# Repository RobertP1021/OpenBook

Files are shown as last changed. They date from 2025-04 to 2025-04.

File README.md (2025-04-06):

# OpenBook

## Diagrama



## Bill Of Materials

| Componenta | Datasheet | Model |
|---|---|---|
| ESP32-C6-WROOM-1-N8 | [Datasheet](https://www.espressif.com/sites/default/files/documentation/esp32-c6_datasheet_en.pdf) | [Model](https://www.snapeda.com/parts/ESP32-C6-WROOM-1-N8/Espressif+Systems/view-part/?ref=eda) |
| W25Q512JVEIQ | [Datasheet](https://www.winbond.com/resource-files/W25Q512JV%20RevI%2005132020%20Plus.pdf) | [Model](https://www.snapeda.com/parts/W25Q512JVEIQ/Winbond+Electronics/view-part/?ref=eda) |
| DS3231SN# | [Datasheet](https://datasheets.maximintegrated.com/en/ds/DS3231.pdf) | [Model](https://www.snapeda.com/parts/DS3231SN%23/Analog+Devices/view-part/?ref=eda) |
| MAX17048G+T10 | [Datasheet](https://datasheets.maximintegrated.com/en/ds/MAX17048-MAX17049.pdf) | [Model](https://www.snapeda.com/parts/MAX17048G+T10/Analog+Devices/view-part/?ref=eda) |
| BME688 | [Datasheet](https://www.bosch-sensortec.com/media/boschsensortec/downloads/datasheets/bst-bme688-ds000.pdf) | [Model](https://www.snapeda.com/parts/BME680/Bosch/view-part/?welcome=home) |
| MCP73831 | [Datasheet](https://ww1.microchip.com/downloads/en/DeviceDoc/20001984g.pdf) | [Model](https://www.snapeda.com/parts/MCP73831T-2ACI-OT/Microchip/view-part/?ref=eda) |
| BD5229G-TR | [Datasheet](https://fscdn.rohm.com/en/products/databook/datasheet/ic/power/voltage_detector/bd52xxg-e.pdf) | [Model](https://componentsearchengine.com/part-view/BD5229G-TR/ROHM%20Semiconductor) |
| USBLC6-2SC6Y | [Datasheet](https://www.st.com/resource/en/datasheet/usblc6-2.pdf) | [Model](https://www.snapeda.com/parts/USBLC6-2SC6Y/STMicroelectronics/view-part/?ref=eda) |
| 112A-TAAR-R03 | [Datasheet](https://www.attend.com.tw/sites/default/files/2022-05/112A-TAAR-R03.pdf) | [Model](https://www.snapeda.com/parts/112A-TAAR-R03/ATTEND/view-part/?ref=eda) |
| FH34SRJ-24S-0.5SH | [Datasheet](https://www.hirose.com/product/document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) | [Model](https://www.snapeda.com/parts/FH34SRJ-24S-0.5SH(99)/Hirose/view-part/?ref=eda) |
| DMG2305UX-7 | [Datasheet](https://www.diodes.com/assets/Datasheets/DMG2305UX.pdf) | [Model](https://www.snapeda.com/parts/DMG2305UX-7/Diodes%20Inc./view-part/?ref=eda) |
| SI1308EDL-T1-GE3 | [Datasheet](https://www.vishay.com/docs/68732/si1308edl.pdf) | [Model](https://www.snapeda.com/parts/SI1308EDL-T1-GE3/Vishay+Siliconix/view-part/?ref=snap) |
| MBR0530 | [Datasheet](https://www.onsemi.com/pdf/datasheet/mbr0520lt1-d.pdf) | [Model](https://www.snapeda.com/parts/MBR0530/Onsemi/view-part/?ref=eda) |
| PGB1010603MR | [Datasheet](https://www.littelfuse.com/media?itemid=3d1e98b7-4d37-463c-9380-c56c83b11c3c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) | [Model](https://www.snapeda.com/parts/PGB1010603MR/Littelfuse/view-part/?ref=eda) |
| XC6220A331MR-G | [Datasheet](https://www.torexsemi.com/file/xc6220/XC6220.pdf) | [Model](https://www.snapeda.com/parts/XC6220A331MR-G/Torex+Semiconductor/view-part/?ref=eda) |
| EVQPUJ02K | [Datasheet](https://industrial.panasonic.com/cdbs/www-data/pdf/ATV0000/ATV0000CE5.pdf) | [Model](https://www.snapeda.com/parts/EVQPUJ02K/Panasonic/view-part/?ref=eda) |
| GDEH0154D67 | [Datasheet](https://www.good-display.com/companyfile/203.html) | [Model](https://www.good-display.com/product/207.html) |
| CPH3225A | [Datasheet](https://www.sii.co.jp/en/quartz/files/2021/03/CPH3225A_E.pdf) | [Model](https://www.snapeda.com/parts/CPH3225A/Seiko+Instruments/view-part/?ref=eda) |

## Functionalitatea hardware

Proiectul foloseste un ESP32-C6 ca microcontroller central, cu urmatoarele componente principale:

1. **Display E-Ink (GDEH0154D67)** - afisaj de 1.54" cu 200x200 pixeli conectat prin SPI, perfect pentru afisarea datelor cu consum minim de energie, deoarece consuma curent doar la actualizarea ecranului.

2. **Memorie Flash externa (W25Q512JVEIQ)** - 64MB de stocare SPI pentru date, configuratii si loguri cand dispozitivul este in modul deep sleep.

3. **Senzor de mediu (BME688)** - masoara temperatura, umiditatea, presiunea atmosferica si calitatea aerului, conectat prin I2C.

4. **Ceas RTC (DS3231)** - mentine ora exacta chiar si cand dispozitivul este oprit, conectat prin I2C.

5. **Sistem de alimentare**: 
   - Baterie LiPo 3.7V
   - Circuit de incarcare (MCP73831)
   - Monitor baterie (MAX17048G)
   - Regulator LDO 3.3V (XC6220A331MR-G)
   - Convertor 5V (pentru componente care necesita 5V)

6. **Interfata USB-C** - pentru incarcare si comunicatii, cu protectie ESD (USBLC6-2SC6Y).

7. **Butoane tactile (EVQPUJ02K)** - 3 butoane pentru interfata utilizator.

8. **Slot card microSD** - pentru stocarea datelor in volum mare.

## Descrierea pinilor ESP32-C6

- **GPIO1-2**: Magistrala I2C principala pentru conectarea senzorilor si RTC-ului DS3231, fiind pinii hardware dedicati pentru I2C.

- **GPIO3**: Pin RESET pentru reinitializarea sistemului.

- **GPIO4**: SS_SD pentru selectarea cardului microSD, parte a interfetei SPI dedicate cardului.

- **GPIO5**: Pin EPD_DC pentru controlul displayului E-Ink (Data/Command).

- **GPIO6**: Pin SPI SCK (clock) utilizat pentru comunicatia cu displayul si alte dispozitive SPI.

- **GPIO7**: Pin MOSI pentru transferul de date spre dispozitivele SPI.

- **GPIO8-9**: Pini pentru interfata RTC (32kHz si INT_RTC), utilizati pentru wake-up si sincronizare.

- **GPIO10**: Pin pentru controlul FLASH_CS, selectand memoria flash externa.

- **GPIO11**: Pin EPD_CS pentru selectarea displayului E-Ink.

- **GPIO12**: Pin EPD_RST pentru resetarea displayului E-Ink.

- **GPIO13-14**: Pini USB_D- si USB_D+ pentru comunicatia USB.

- **GPIO15**: Pin IO/BOOT pentru controlul bootarii sistemului.

- **GPIO16-18**: Pini pentru controlul displayului e-ink (EPD_3V3, EPD_BUSY).

- **GPIO19-21**: Pini SCL, SDA pentru o secunda interfata I2C folosita pentru comunicatie cu senzorii adaugati.

- **GPIO22-23**: Pini pentru control I/O general si semnale de control pentru display.

- **GPIO26-28**: Pini pentru LED-uri de status si controlul modulului.

## Poze


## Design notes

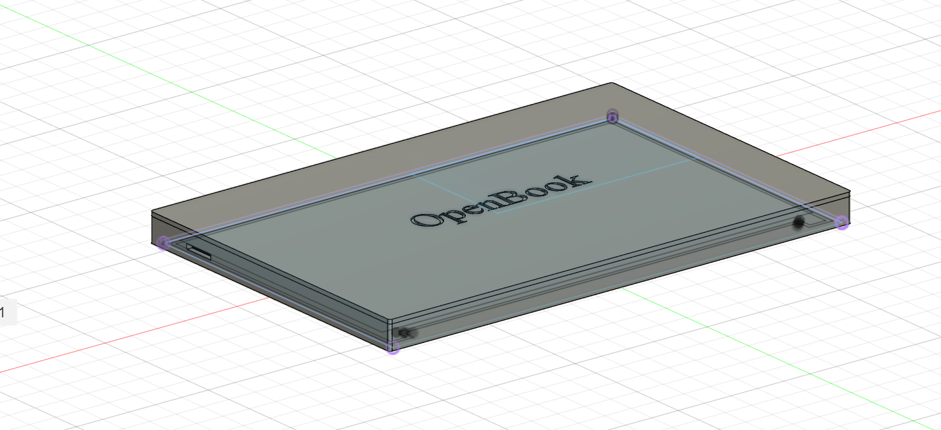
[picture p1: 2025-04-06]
Images/Screenshot 2025-04-06 211127.png

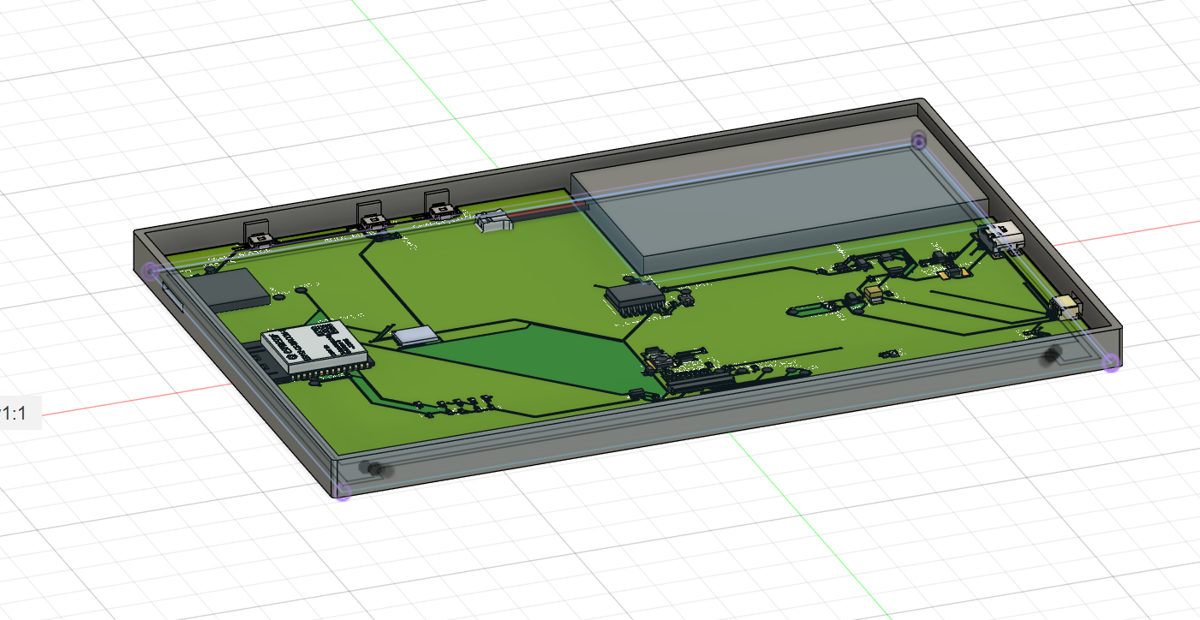
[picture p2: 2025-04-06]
Images/Screenshot 2025-04-06 211154.png

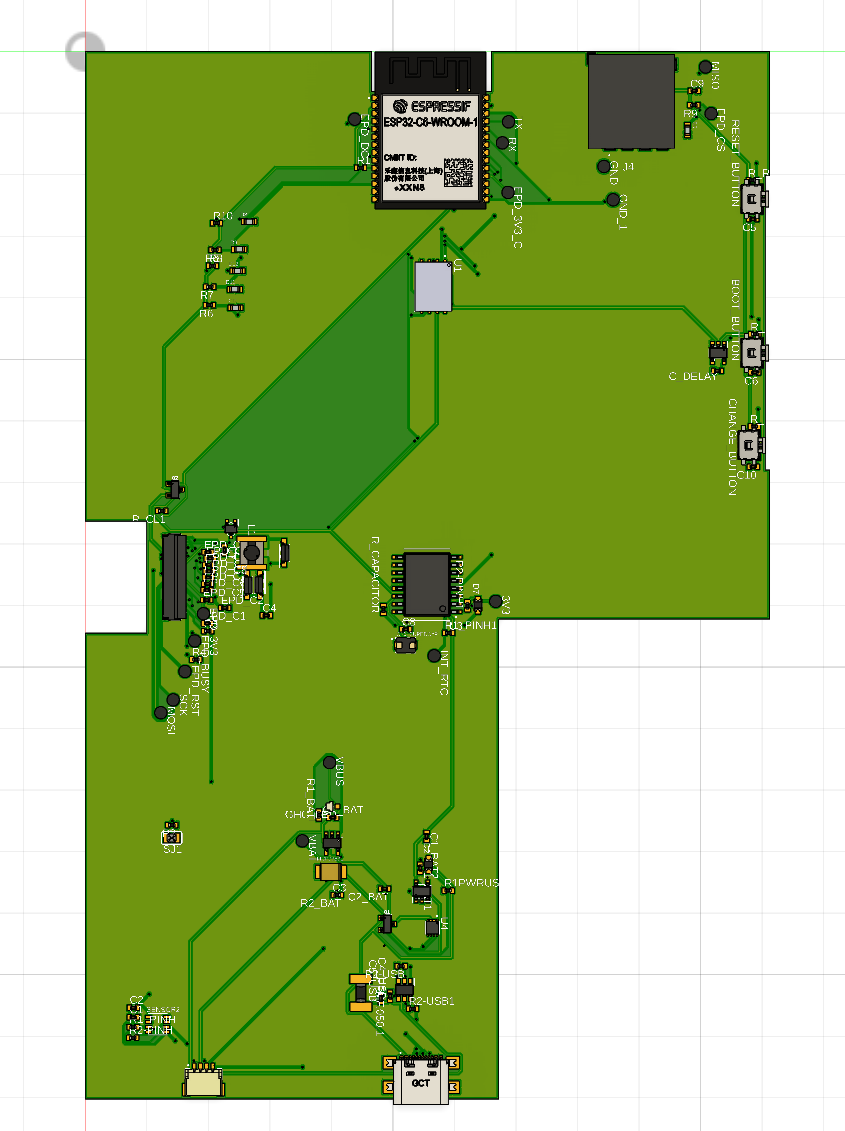
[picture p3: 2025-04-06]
Images/Screenshot 2025-04-06 211323.png

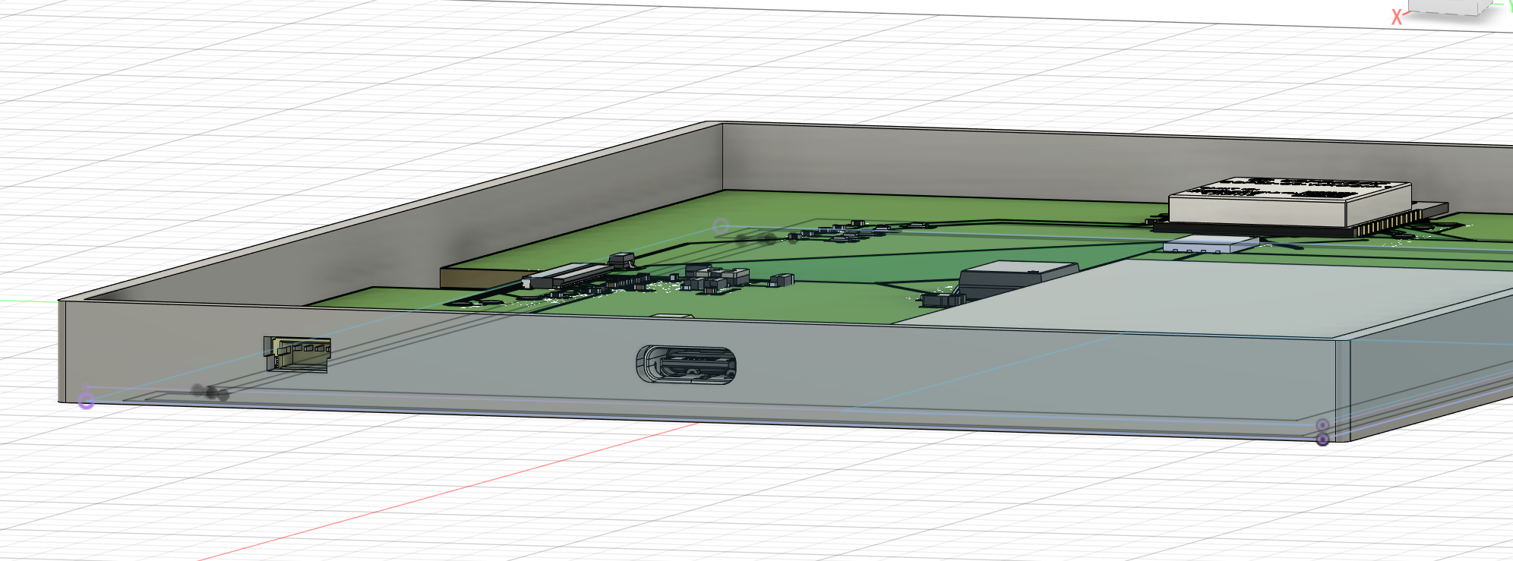
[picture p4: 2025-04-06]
Images/Screenshot 2025-04-06 211255.png

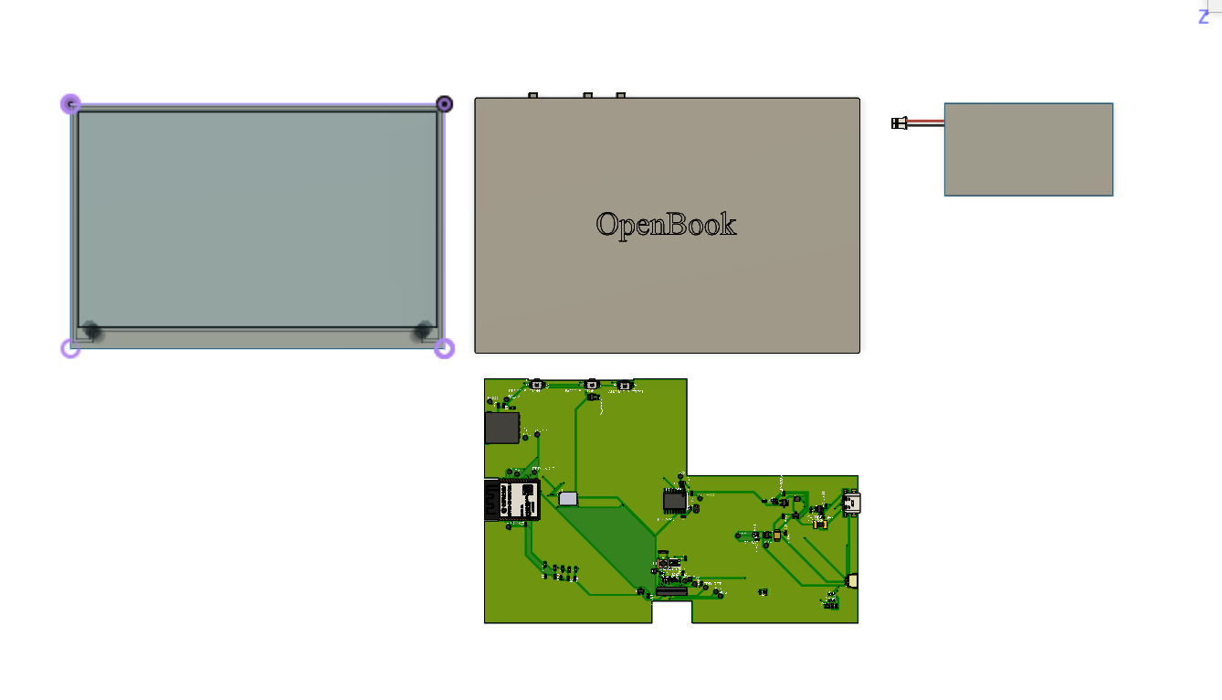
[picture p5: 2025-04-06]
Images/Screenshot 2025-04-06 211106.png

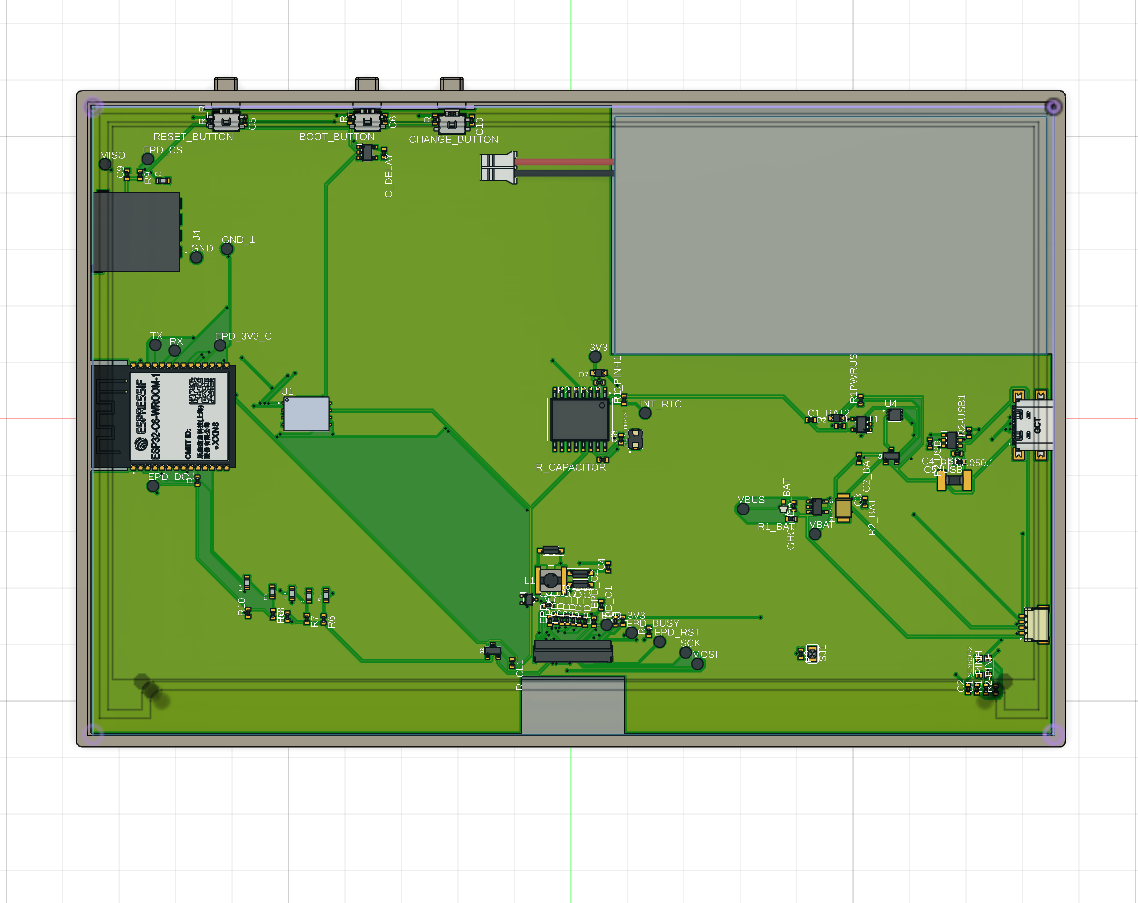
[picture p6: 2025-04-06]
Images/Screenshot 2025-04-06 211142.png

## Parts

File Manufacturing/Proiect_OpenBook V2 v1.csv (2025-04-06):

Qty | Value | Device | Package | Parts | Description | ARROW_PART_NUMBER | ARROW_PRICE-STOCK | AVAILABILITY | CENTROID_NOT_SPECIFIED | CHECK_PRICES | COPYRIGHT | DATASHEET | DESCRIPTION | DIGIKEY_DESCRIPTION | DIGIKEY_PART_NUMBER | HEIGHT | LEAD_FREE | MANUFACTURER_NAME | MANUFACTURER_PART_NUMBER | MF | MFR_NAME | MOUSER_PART_NUMBER | MOUSER_PRICE-STOCK | MOUSER_TESTING_PART_NUMBER | MOUSER_TESTING_PRICE-STOCK | MP | MPN | PACKAGE | POPULARITY | PREFIX | PRICE | PROD_ID | PURCHASE-URL | ROHS | SNAPEDA_LINK | SPICEMODEL | SPICEPREFIX | TEMPERATURE_RANGE_HIGH | TEMPERATURE_RANGE_LOW | TP_SIGNAL_NAME | VALUE | LCSC Part Number
1 |  | ADAFRUIT_LEDCHIP-LED0603 | ADAFRUIT_CHIP-LED0603 | GHC_LED | LED
1 |  | SJ | SJ | SJ1 | SMD solder JUMPER |  |  |  |  |  |  |  |  |  |  |  |  |  |  |  |  |  |  |  |  |  |  |  | 3
1 | 0.1uF/50V | EAGLE-LTSPICE_CC0402 | ESP32_WROVER_EAGLE-LTSPICE_C0402 | EPD_C5 | CAPACITOR, European symbol |  |  |  |  |  |  |  |  |  |  |  |  |  |  |  |  |  |  |  |  |  |  |  |  |  |  |  |  |  |  | NONE | C
1 | 0.47 | ESP32_WROVER_EAGLE-LTSPICE_RR0402 | ESP32_WROVER_EAGLE-LTSPICE_R0402 | R3 | RESISTOR, European symbol |  |  |  |  |  |  |  |  |  |  |  |  |  |  |  |  |  |  |  |  |  |  |  |  |  |  |  |  |  |  | NONE | R
1 | 100K | ESP32_WROVER_EAGLE-LTSPICE_RR0402 | ESP32_WROVER_EAGLE-LTSPICE_R0402 | R1PWRUSB | RESISTOR, European symbol |  |  |  |  |  |  |  |  |  |  |  |  |  |  |  |  |  |  |  |  |  |  |  |  |  |  |  |  |  |  | NONE | R
8 | 100nF | EAGLE-LTSPICE_CC0402 | ESP32_WROVER_EAGLE-LTSPICE_C0402 | C1, C2, C4_USB, C6, C8, C9, C10, C_DELAY | CAPACITOR, European symbol |  |  |  |  |  |  |  |  |  |  |  |  |  |  |  |  |  |  |  |  |  |  |  |  |  |  |  |  |  |  | NONE | C
1 | 100uF | RCL_CPOL-EUCT3528 | RCL_CT3528 | C3 | POLARIZED CAPACITOR, European symbol |  |  |  |  |  |  |  |  |  |  |  |  |  |  |  |  |  |  |  |  |  |  |  | 0 |  |  |  |  |  |  |  | C
16 | 10K | ESP32_WROVER_EAGLE-LTSPICE_RR0402 | ESP32_WROVER_EAGLE-LTSPICE_R0402 | R1, R1_PINH, R1_PINH1, R2-PINH, R2-PINH1, R4, R5, R6, R7, R8, R9, R10, R_BOOT, R_CHANGE, R_CL1, R_RESET | RESISTOR, European symbol |  |  |  |  |  |  |  |  |  |  |  |  |  |  |  |  |  |  |  |  |  |  |  |  |  |  |  |  |  |  | NONE | R
1 | 10uF | EAGLE-LTSPICE_CC0402 | ESP32_WROVER_EAGLE-LTSPICE_C0402 | C7 | CAPACITOR, European symbol |  |  |  |  |  |  |  |  |  |  |  |  |  |  |  |  |  |  |  |  |  |  |  |  |  |  |  |  |  |  | NONE | C
1 | 112A-TAAR-R03_ATTEND | 112A-TAAR-R03_ATTEND | 112ATAARR03ATTEND | J4 | Micro SD Card Socket, Push-Push Type, Top Mount, SMT, H=1.83mm, 10u |  |  |  |  |  |  |  | Micro SD Card Socket | Push-Push Type | Top Mount | SMT | H=1.83mm | 10u |  |  | 1.9mm |  | ATTEND | 112A-TAAR-R03 ATTEND
1 | 15 | ESP32_WROVER_EAGLE-LTSPICE_RR0402 | ESP32_WROVER_EAGLE-LTSPICE_R0402 | R_CAPACITOR | RESISTOR, European symbol |  |  |  |  |  |  |  |  |  |  |  |  |  |  |  |  |  |  |  |  |  |  |  |  |  |  |  |  |  |  | NONE | R
1 | 1uF | EAGLE-LTSPICE_CC0402 | ESP32_WROVER_EAGLE-LTSPICE_C0402 | C5 | CAPACITOR, European symbol |  |  |  |  |  |  |  |  |  |  |  |  |  |  |  |  |  |  |  |  |  |  |  |  |  |  |  |  |  |  | NONE | C
9 | 1uF/50V | EAGLE-LTSPICE_CC0402 | ESP32_WROVER_EAGLE-LTSPICE_C0402 | EPD_C1, EPD_C2, EPD_C6, EPD_C7, EPD_C8, EPD_C9, EPD_C10, EPD_C11, EPD_C12 | CAPACITOR, European symbol |  |  |  |  |  |  |  |  |  |  |  |  |  |  |  |  |  |  |  |  |  |  |  |  |  |  |  |  |  |  | NONE | C
1 | 2.2 | ESP32_WROVER_EAGLE-LTSPICE_RR0402 | ESP32_WROVER_EAGLE-LTSPICE_R0402 | R2 | RESISTOR, European symbol |  |  |  |  |  |  |  |  |  |  |  |  |  |  |  |  |  |  |  |  |  |  |  |  |  |  |  |  |  |  | NONE | R
1 | 200 | ESP32_WROVER_EAGLE-LTSPICE_RR0402 | ESP32_WROVER_EAGLE-LTSPICE_R0402 | R1_BAT | RESISTOR, European symbol |  |  |  |  |  |  |  |  |  |  |  |  |  |  |  |  |  |  |  |  |  |  |  |  |  |  |  |  |  |  | NONE | R
2 | 20V/4.2A/52mO/1.4W | ESP32_WROVER_SPARKFUN-DISCRETESEMI_MOSFET_PCH-DMG2305UX-7 | ESP32_WROVER_SPARKFUN-DISCRETESEMI_SOT23-3 | Q1, Q2 | P-channel MOSFETs |  |  |  |  |  |  |  |  |  |  |  |  |  |  |  |  |  |  |  |  |  |  |  |  |  |  | TRAN-14388 |  |  |  |  |  |  |  |  | 20V/4.2A/52mO/1.4W
1 | 2K | ESP32_WROVER_EAGLE-LTSPICE_RR0402 | ESP32_WROVER_EAGLE-LTSPICE_R0402 | R2_BAT | RESISTOR, European symbol |  |  |  |  |  |  |  |  |  |  |  |  |  |  |  |  |  |  |  |  |  |  |  |  |  |  |  |  |  |  | NONE | R
5 | 4.7uF | EAGLE-LTSPICE_CC0402 | ESP32_WROVER_EAGLE-LTSPICE_C0402 | C1_BAT, C1_BAT1, C1_BAT2, C2_BAT, C5_USB | CAPACITOR, European symbol |  |  |  |  |  |  |  |  |  |  |  |  |  |  |  |  |  |  |  |  |  |  |  |  |  |  |  |  |  |  | NONE | C
1 | 4.7uF/25V | EAGLE-LTSPICE_CC0402 | ESP32_WROVER_EAGLE-LTSPICE_C0402 | C4 | CAPACITOR, European symbol |  |  |  |  |  |  |  |  |  |  |  |  |  |  |  |  |  |  |  |  |  |  |  |  |  |  |  |  |  |  | NONE | C
2 | 5k1 | ESP32_WROVER_EAGLE-LTSPICE_RR0402 | ESP32_WROVER_EAGLE-LTSPICE_R0402 | R2-USB, R2-USB1 | RESISTOR, European symbol |  |  |  |  |  |  |  |  |  |  |  |  |  |  |  |  |  |  |  |  |  |  |  |  |  |  |  |  |  |  | NONE | R
1 | 68uH | 744043680IND_4828-WE-TPC_WRE | IND_4828-WE-TPC_WRE | L1 |  |  |  |  |  |  | Copyright (C) 2024 Ultra Librarian. All rights reserved. |  |  |  |  |  |  |  | 744043680 |  | Wurth Electronics
1 | BD5229G-TR | BD5229G-TR | SOT95P280X125-5N | IC1 | Voltage Detector with Adjustable Delay Time: CMOS processes are utilized to develop high precision, low current consumption CMOS reset ICs that allow arbitrary setting of the delay time. The extensive lineup includes both Nch Open Drain and CMOS output types in a wide range of detection voltages (from 2.3V to 6.0V, in 0.1V steps), enabling selection of the ideal solution based on customer requirements. In addition, the entire series is of course both lead-free and RoHS-compliant. |  |  |  |  |  |  |  | Voltage Detector with Adjustable Delay Time: CMOS processes are utilized to develop high precision | low current consumption CMOS reset ICs that allow arbitrary setting of the delay time. The extensive lineup includes both Nch Open Drain and CMOS output types in a wide range of detection voltages (from 2.3V to 6.0V | in 0.1V steps) | enabling selection of the ideal solution based on customer requirements. In addition | the entire series is of course both lead-free and RoHS-compliant. |  |  | 1.25mm |  | ROHM Semiconductor | BD5229G-TR |  |  | 755-BD5229G-TR | https://www.mouser.co.uk/ProductDetail/ROHM-Semiconductor/BD5229G-TR?qs=4kLU8WoGk0vvnhrrYwdszw%3D%3D
3 | BUTTON_CUSYOMV1 | BUTTON_CUSYOMV1 | MYBUTTON | BOOT_BUTTON, CHANGE_BUTTON, RESET_BUTTON
1 | CPH3225A | CPH3225A | CAPCP3225X100N | C10_SUPERCAP | Cap 0.011F 3.3V 1210 Flat Check availability |  |  | Not in stock |  | https://www.snapeda.com/parts/CPH3225A/Seiko+Instruments/view-part/?ref=eda |  |  | 11 mF (EDLC) Supercapacitor 3.3 V 1210 (3225 Metric) - - |  |  |  |  |  |  | Seiko Instruments |  |  |  |  |  | CPH3225A |  | 1210 Seiko |  |  | None |  | https://www.snapeda.com/api/url_track_click_mouser/?unipart_id=562593&manufacturer=Seiko Instruments&part_name=CPH3225A&search_term=None |  | https://www.snapeda.com/parts/CPH3225A/Seiko+Instruments/view-part/?ref=snap
1 | DS3231SN# | DS3231SN# | SOIC127P1032X265-16N | U3 | Real Time Clock Serial 16-Pin SOIC W T/R Check availability |  |  | In Stock |  | https://www.snapeda.com/parts/DS3231SN%23/Analog+Devices/view-part/?ref=eda |  |  | Extremely Accurate I²C-Integrated RTC/TCXO/Crystal |  |  |  |  |  |  | Analog Devices |  |  |  |  |  | DS3231SN# |  | SOIC-16 Maxim |  |  | None |  | https://www.snapeda.com/api/url_track_click_mouser/?unipart_id=99048&manufacturer=Analog Devices&part_name=DS3231SN#&search_term=None |  | https://www.snapeda.com/parts/DS3231SN%23/Analog+Devices/view-part/?ref=snap
1 | ESP32-C6-WROOM-1-N8 | ESP32-C6-WROOM-1-N8 | XCVR_ESP32-C6-WROOM-1-N8 | U2 | Check availability |  |  | In Stock |  | https://www.snapeda.com/parts/ESP32-C6-WROOM-1-N8/Espressif+Systems/view-part/?ref=eda |  |  | Multiprotocol Modules ESP32-C6 module | Wi-Fi 6 in 2.4 GHz band | Bluetooth 5 | Zigbee 3.0 and Thread. ESP34-WROOM Compatible - ENGINEERING SAMPLE |  |  |  |  |  |  | Espressif Systems |  |  |  |  |  | ESP32-C6-WROOM-1-N8 |  | None |  |  | None |  |  |  | https://www.snapeda.com/parts/ESP32-C6-WROOM-1-N8/Espressif+Systems/view-part/?ref=snap
1 | ESP32C6_VARISTORCN1812 | ESP32C6_VARISTORCN1812 | ESP32C6_VARISTOR_CT/CN1812 | PFMF.050.1 | VARISTOR |  |  |  |  |  |  |  |  |  |  |  |  |  |  |  |  |  |  |  |  |  |  |  | 0
2 | ESP32_WROVER_AVX---SD0805S020S1R0_AVX_SD0805S020S1R0_0_0AVX_SD0805S020S1R0_0_0 | ESP32_WROVER_AVX---SD0805S020S1R0_AVX_SD0805S020S1R0_0_0AVX_SD0805S020S1R0_0_0 | ESP32_WROVER_AVX---SD0805S020S1R0_AVX_SD0805S020S1R0_0 | D2, D7 | Schottky Barrier Rectifier Diode |  |  |  | No |  |  | http://datasheets.avx.com/schottky.pdf |  | DIODE SCHOTTKY 20V 1A 0805 | 478-7800-1-ND |  | yes |  |  | AVX |  | 581-SD0805S020S1R0 |  |  |  |  |  | 0805 (2012 metric) |  | D |  |  |  | yes |  |  |  | +125°C | -55°C
1 | ESP32_WROVER_BME680_BME680 | ESP32_WROVER_BME680_BME680 | ESP32_WROVER_BME680_PSON80P300X300X100-8N | SENSOR2 | Integrated Environmental Unit |  |  | Unavailable |  |  |  |  | Integrated Environmental Unit |  |  |  |  |  |  | Bosch Sensortec |  |  |  |  |  | BME680 |  | LGA-8 Bosch Tools |  |  | None
1 | ESP32_WROVER_SPARKFUN-IC-POWER_MCP73831 | ESP32_WROVER_SPARKFUN-IC-POWER_MCP73831 | ESP32_WROVER_SPARKFUN-IC-POWER_SOT23-5 | MCP73831 | MCP73831T Li-Ion, Li-Pol Controller |  |  |  |  |  |  |  |  |  |  |  |  |  |  |  |  |  |  |  |  |  |  |  |  |  |  | IC-09995
1 | FH34SRJ-24S-0.5SH_99_ | FH34SRJ-24S-0.5SH_99_ | FH34SRJ24S05SH99 | J1 | (0.50mm) Surface Mount, Right Angle |  |  |  |  |  |  |  | 24 Position FFC | FPC Connector Contacts | (0.50mm) Surface Mount | Right Angle |  |  | 1.1mm |  | Hirose | FH34SRJ-24S-0.5SH(99) |  |  | 798-FH34SRJ24S05SH99 | https://www.mouser.co.uk/ProductDetail/Hirose-Connector/FH34SRJ-24S-0.5SH99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
1 | MAX17048G+T10 | MAX17048G+T10 | SON50P200X200X80-9N | U4 | Check availability |  |  | In Stock |  | https://www.snapeda.com/parts/MAX17048G+T10/Analog+Devices/view-part/?ref=eda |  |  | 3µA 1-Cell/2-Cell Fuel Gauge with ModelGauge |  |  |  |  |  |  | Analog Devices |  |  |  |  |  | MAX17048G+T10 |  | TDFN-8 Maxim |  |  | None |  | https://www.snapeda.com/api/url_track_click_mouser/?unipart_id=329239&manufacturer=Analog Devices&part_name=MAX17048G+T10&search_term=None |  | https://www.snapeda.com/parts/MAX17048G+T10/Analog+Devices/view-part/?ref=snap
3 | MBR0530 | MBR0530 | SOD3716X135N | D3, D4, D5 | ON SEMICONDUCTOR - MBR0530 - DIODE, SCHOTTKY, 0.5A, 30V, SOD-123 |  |  | In Stock |  | https://www.snapeda.com/parts/MBR0530/Onsemi/view-part/?ref=eda |  |  | Diode Schottky 30 V 500mA Surface Mount SOD-123 |  |  |  |  |  |  | ON Semiconductor |  |  |  |  |  | MBR0530 |  | SOD-123-2 ON Semiconductor |  |  | None |  | https://www.snapeda.com/api/url_track_click_mouser/?unipart_id=179458&manufacturer=ON Semiconductor&part_name=MBR0530&search_term=None |  | https://www.snapeda.com/parts/MBR0530/Onsemi/view-part/?ref=snap
6 | PGB1010603MR | PGB1010603MR | DIOC1608X36N | D6, D8, D9, D10, D11, D12 | Check availability |  |  | In Stock |  | https://www.snapeda.com/parts/PGB1010603MR/Littelfuse/view-part/?ref=eda |  |  | 150V (Typ) Clamp - Ipp Tvs Diode Surface Mount 0603 (1608 Metric) |  |  |  |  |  |  | Littelfuse Inc. |  |  |  |  |  | PGB1010603MR |  | 0603 Littelfuse Inc. |  |  | None |  | https://www.snapeda.com/api/url_track_click_mouser/?unipart_id=5659453&manufacturer=Littelfuse Inc.&part_name=PGB1010603MR&search_term=None |  | https://www.snapeda.com/parts/PGB1010603MR/Littelfuse/view-part/?ref=snap
1 | QWIIC_RIGHT_ANGLE | QWIIC_CONNECTORJS-1MM | JST04_1MM_RA | J3 | SparkFun I2C Standard Qwiic Connector |  |  |  |  |  |  |  |  |  |  |  |  |  |  |  |  |  |  |  |  |  |  |  |  |  |  | CONN-13694 |  |  |  |  |  |  |  |  | QWIIC_RIGHT_ANGLE
1 | SAMACSYS_PARTS_USB4110-GF-A | SAMACSYS_PARTS_USB4110-GF-A | SAMACSYS_PARTS_USB4110GFA | J2 | CONN USB 2.0 TYPE-C R/A SMT |  |  |  |  |  |  |  | CONN USB 2.0 TYPE-C R/A SMT |  |  | 3.26mm |  | GCT (GLOBAL CONNECTOR TECHNOLOGY) | USB4110-GF-A |  |  | 640-USB4110-GF-A | https://www.mouser.co.uk/ProductDetail/GCT/USB4110-GF-A?qs=KUoIvG%2F9IlYiZvIXQjyJeA%3D%3D
1 | SI1308EDL-T1-GE3 | SI1308EDL-T1-GE3 | SOT65P210X110-3N | Q3 | MOSFET N-Ch 30V 1.5A TrenchFET SC70 Vishay Si1308EDL-T1-GE3 N-channel MOSFET Transistor, 1.5 A, 30 V, 3-Pin SC-70 |  |  | In Stock |  | https://www.snapeda.com/parts/SI1308EDL-T1-GE3/Vishay+Siliconix/view-part/?ref=eda |  |  | Si1308EDL-T1-GE3 N-channel MOSFET Transistor | 1.5 A | 30 V | 3-Pin SC-70 | Siliconix / Vishay SI1308EDL-T1-GE3 |  |  |  |  |  |  | Vishay Siliconix |  |  |  |  |  | SI1308EDL-T1-GE3 |  | SOT-323 Vishay Semiconductor |  |  | None |  | https://www.snapeda.com/api/url_track_click_mouser/?unipart_id=274603&manufacturer=Vishay Siliconix&part_name=SI1308EDL-T1-GE3&search_term=None |  | https://www.snapeda.com/parts/SI1308EDL-T1-GE3/Vishay+Siliconix/view-part/?ref=snap
17 | TPTP20R | TPTP20R | TP20R | 3V3, EPD_3V3, EPD_3V3_C, EPD_BUSY, EPD_CS, EPD_DC, EPD_RST, GND, GND_1, INT_RTC, MISO, MOSI, RX, SCK, TX, VBAT, VBUS | Test pad |  |  |  |  |  |  |  |  |  |  |  |  |  |  |  |  |  |  |  |  |  |  |  | 2
1 | USBLC6-2SC6Y | USBLC6-2SC6Y | SOT95P280X145-6N | D1 | Low Cap. ESD Protection Auto SOT-23-6 STMicroelectronics USBLC6-2SC6Y, Dual Uni-Directional TVS Diode Array, 6-Pin SOT-23 |  |  | In Stock |  | https://www.snapeda.com/parts/USBLC6-2SC6Y/STMicroelectronics/view-part/?ref=eda |  |  | 17V Clamp 5A (8/20µs) Ipp Tvs Diode Surface Mount SOT-23-6 |  |  |  |  |  |  | STMicroelectronics |  |  |  |  |  | USBLC6-2SC6Y |  | SOT-23-6 STMicroelectronics |  |  | None |  |  |  | https://www.snapeda.com/parts/USBLC6-2SC6Y/STMicroelectronics/view-part/?ref=snap
1 | W25Q512JVEIQ | W25Q512JVEIQ | SON127P600X800X80-9N | U1 | Check availability |  |  | In Stock |  | https://www.snapeda.com/parts/W25Q512JVEIQ/Winbond+Electronics/view-part/?ref=eda |  |  | FLASH - NOR Memory IC 512Mb (64M x 8) SPI - Quad I/O 133 MHz 8-WSON (8x6) |  |  |  |  |  |  | Winbond Electronics |  |  |  |  |  | W25Q512JVEIQ |  | Package |  |  | None |  |  |  | https://www.snapeda.com/parts/W25Q512JVEIQ/Winbond+Electronics/view-part/?ref=snap
1 | XC6220A331MR-G | XC6220A331MR-G | SOT95P280X120-5N | IC4 | LDO Voltage Regulators |  |  |  |  |  |  |  | LDO Voltage Regulators |  |  | 1.2mm |  | Torex | XC6220A331MR-G |  |  | 865-XC6220A331MR-G | https://www.mouser.co.uk/ProductDetail/Torex-Semiconductor/XC6220A331MR-G?qs=AsjdqWjXhJ8ZSWznL1J0gg%3D%3D

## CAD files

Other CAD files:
Mechanical/OpenBook Enclosure final.f3z

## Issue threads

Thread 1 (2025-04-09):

GND Pour

MihaiCatalin-Stan, 2025-04-09:
# Issue

GND pour has empty patches both on top and on bottom as seen in the pictures below.

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

# Fix guide
* Open the PCB file
* Click on "Route", and drag a wire next to one of the empty patches
* Create a via through the gnd plane, and draw the gnd wire on the other layer all the way to the empty patch
* Create another via to connect it back to the desired layer

Closed 2025-04-14.

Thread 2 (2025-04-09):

Vias Number

MihaiCatalin-Stan, 2025-04-09:
# Issue

There are over 100 viases in the pcb project and they appear in disorganised clusters. Try spacing the components to allow wires to pass without as many viases.

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

# Recommendations
* Leave space between the components to allow routing of wires between those components
* Try orienting the components so that wires don't create circles around the board
* Rerouting the pcb might prove more efficient than trying to fix every signal individually

Closed 2025-04-14.

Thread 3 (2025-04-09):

Power route with wrong width

MihaiCatalin-Stan, 2025-04-09:
# Issue

**I2C_PW** has *0.15mm* and is routed both on top layer and bottom layer as seen below

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

# Recommendations
* Add the I2C_PW to the net class created for power routes and make sure the routing width is set to a *minimum of 0.3mm*
* Check if the wires can be routed on top
* If it can't, reroute the wires on its path
* If all else fails, make sure the number of viases on this route stays at a minimum

# Other mentions
* ***This issue can and should be solved at the same as the previous issue: #2 ***

Closed 2025-04-14.

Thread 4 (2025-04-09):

Right angle wires

MihaiCatalin-Stan, 2025-04-09:
# Issue

A few wires have right angles (90 degrees) and it is recommended to fix them. Such examples include but are not limited to: EPD_CS on bottom next to ESP32, SCL and SDA on bottom next between QWIIC and USB-C, 3V3 on top next to boot button

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

# Recommendations
* Disable the view of layers that might obstruct your view and of the ground planes
* Check the wiring carefully and fix the wires that create 90 degrees crossroads

Closed 2025-04-14.

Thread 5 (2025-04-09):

Wrong orientation/placement of 3D model components

MihaiCatalin-Stan, 2025-04-09:
# Issue

The LED and one type of transistors are placed on one side (as seen in the pictures below) instead of upright.

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

# Fix Guide
* Open the DeskAssistant library and go to the desired component
* Right click and edit the 3D design
* Make sure the component isn't grounded, if it is, unground it from root
* Move and rotate the component so that its pins or pads allign with the ones highlighted by the 3D environment

Closed 2025-04-14.

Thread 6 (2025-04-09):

Missing 3D design for some components

MihaiCatalin-Stan, 2025-04-09:
# Issue
For some components such as SENSOR2 and the SD Card slot the 3D models are missing

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

# Fix suggestion
* Open the library and right click on the component that presents the issue
* Create new 3D design
* Upload the wanted design
* Align the components' pads with the ones in the model view
* Save, update the library and push to 3D

Closed 2025-04-14.

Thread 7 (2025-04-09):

Missing via stitches on ground plane

MihaiCatalin-Stan, 2025-04-09:
The ground planes are not connected via stitches, neither around the esp module nor anywhere else on the board.

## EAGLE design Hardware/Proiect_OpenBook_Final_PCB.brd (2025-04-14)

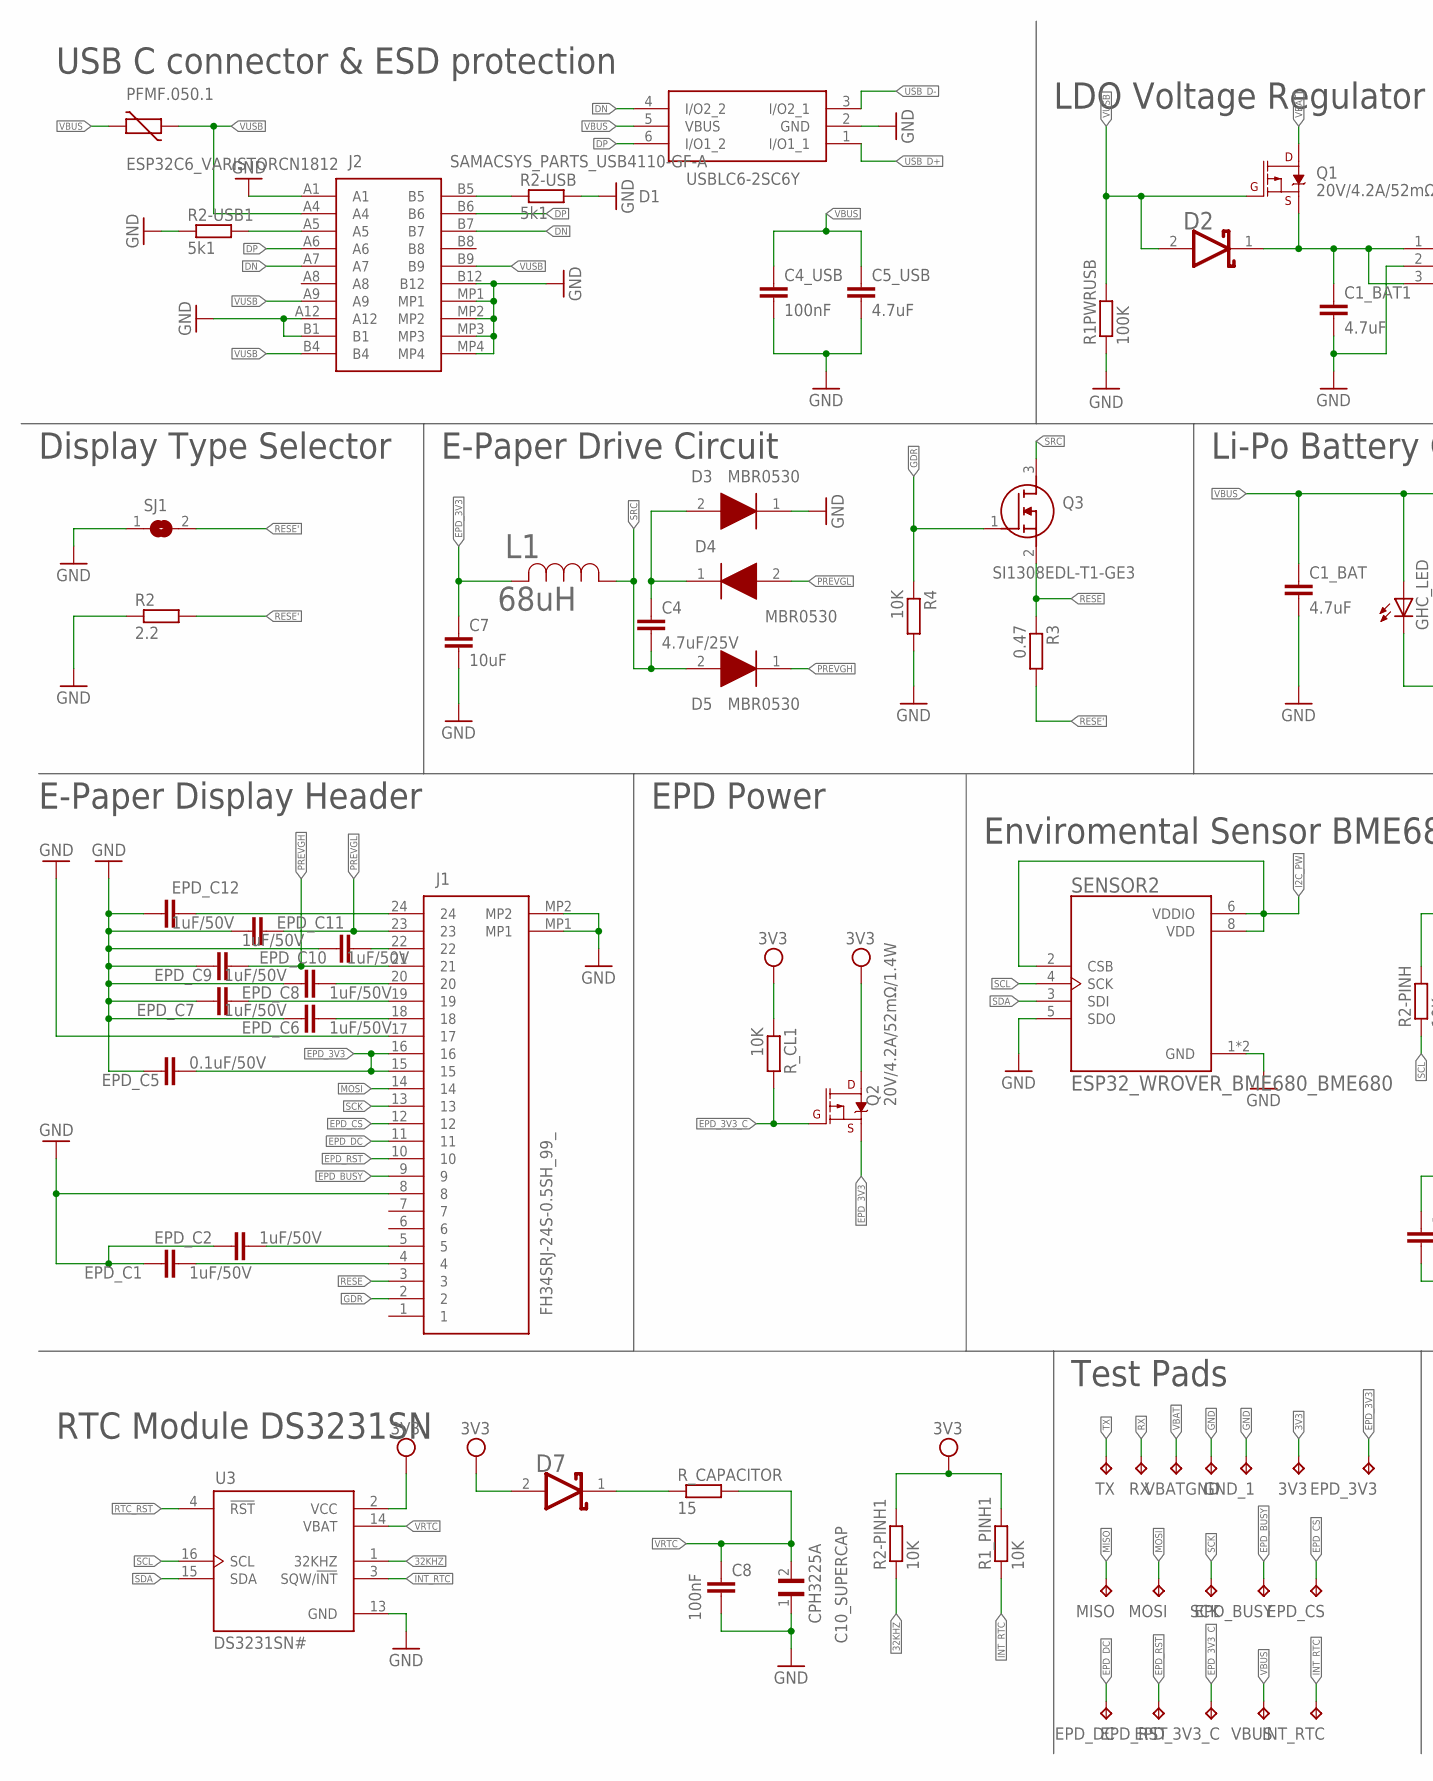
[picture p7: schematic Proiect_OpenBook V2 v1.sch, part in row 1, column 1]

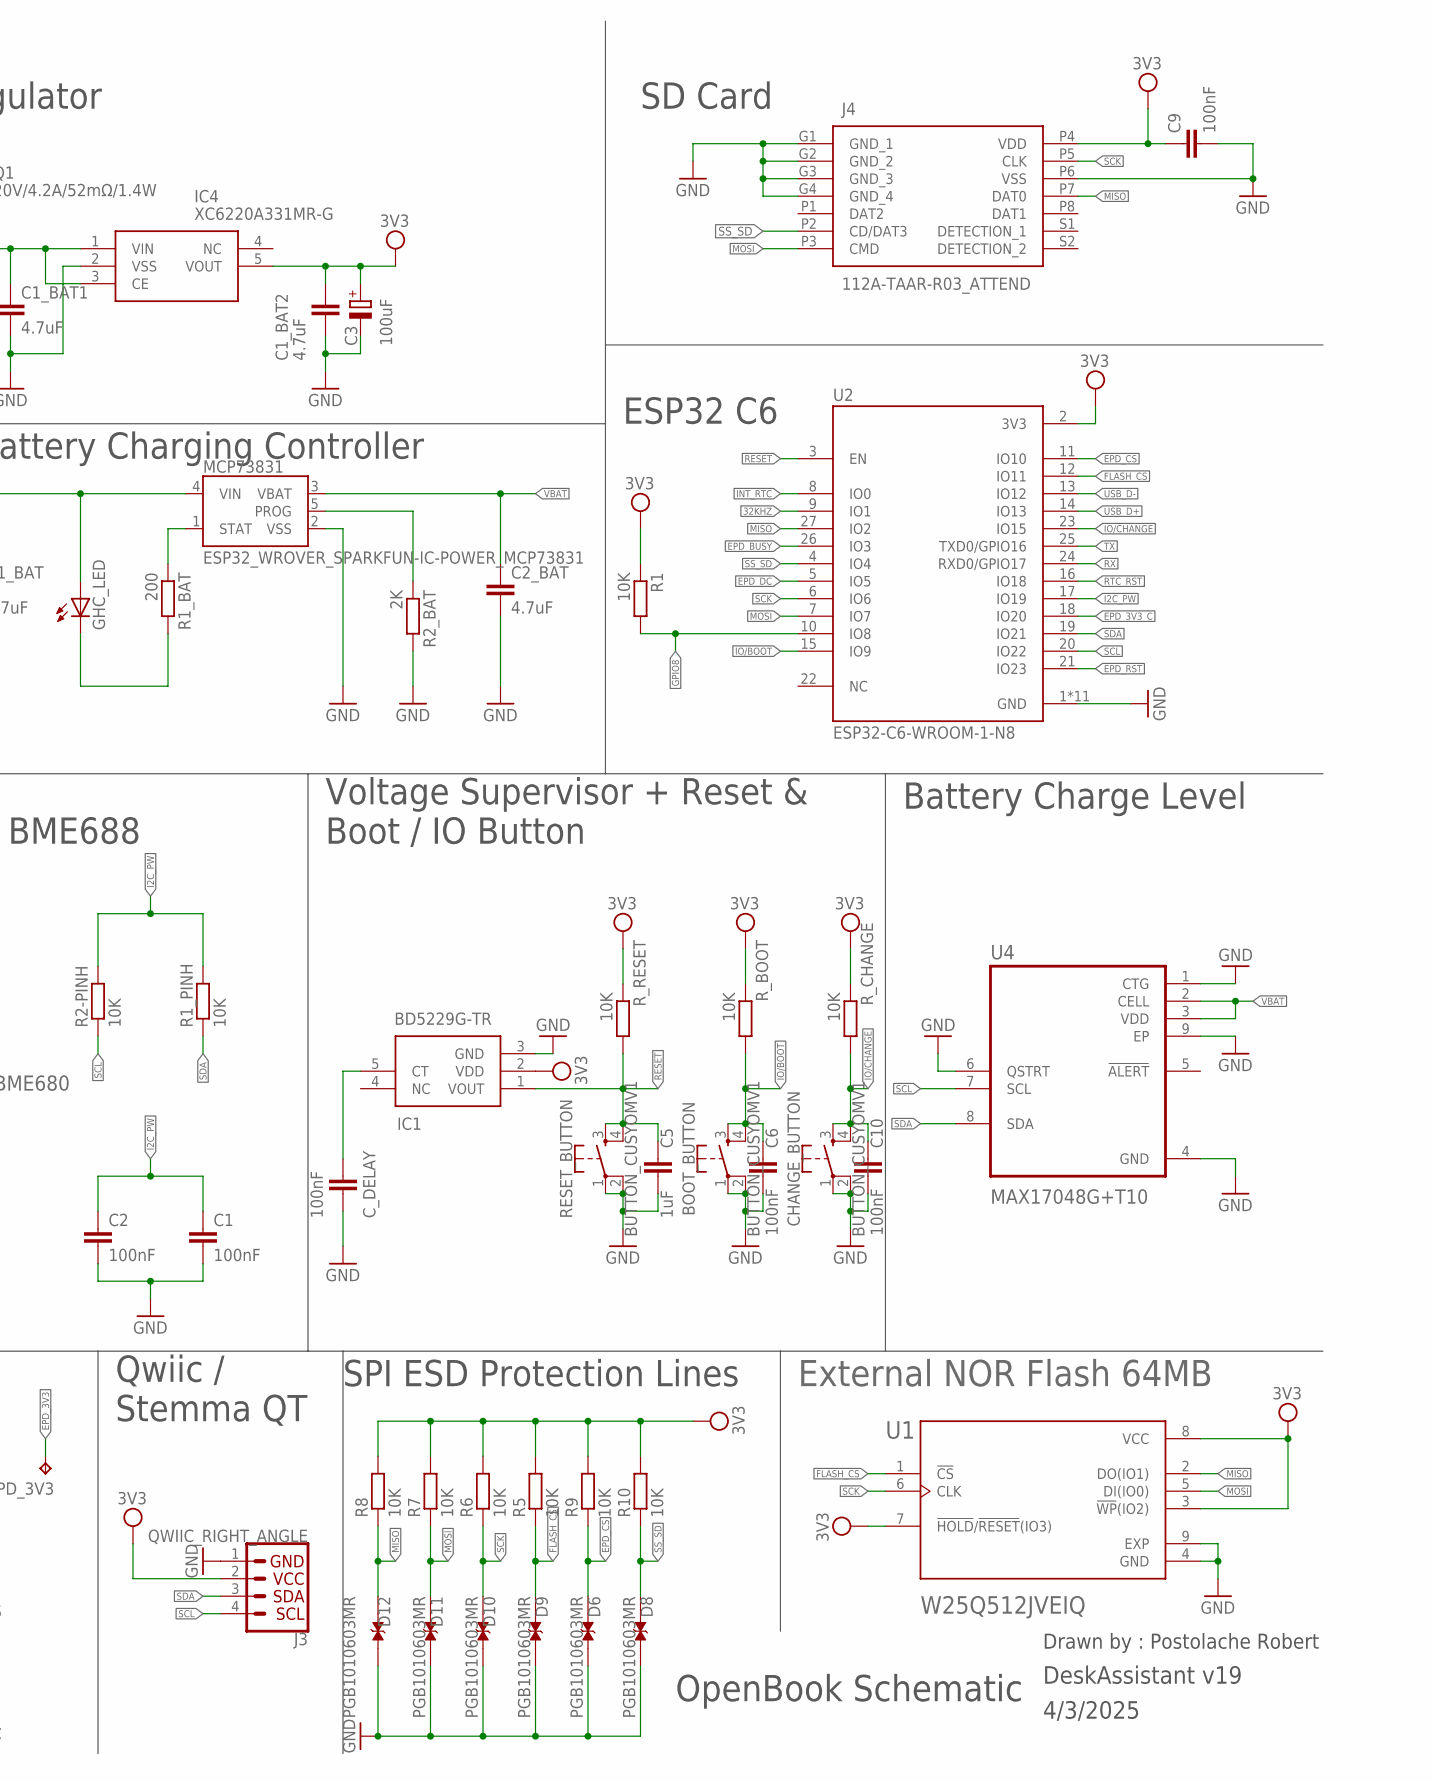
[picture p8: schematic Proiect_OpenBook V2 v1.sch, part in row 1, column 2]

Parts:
3V3: TPTP20R; TP20R
BOOT_BUTTON: BUTTON_CUSYOMV1; MYBUTTON
C1, C2, C4_USB, C6, C8, C9, C10: 100nF; ESP32_WROVER_EAGLE-LTSPICE_C0402
C1_BAT, C1_BAT1, C1_BAT2, C2_BAT, C5_USB: 4.7uF; ESP32_WROVER_EAGLE-LTSPICE_C0402
C3: 100uF; RCL_CT3528
C4: 4.7uF/25V; ESP32_WROVER_EAGLE-LTSPICE_C0402
C5: 1uF; ESP32_WROVER_EAGLE-LTSPICE_C0402
C7: 10uF; ESP32_WROVER_EAGLE-LTSPICE_C0402
C10_SUPERCAP: CPH3225A; CAPCP3225X100N
CHANGE_BUTTON: BUTTON_CUSYOMV1; MYBUTTON
C_DELAY: 100nF; ESP32_WROVER_EAGLE-LTSPICE_C0402
D1: USBLC6-2SC6Y; SOT95P280X145-6N
D2, D7: ESP32_WROVER_AVX---SD0805S020S1R0_AVX_SD0805S020S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; ESP32_WROVER_AVX---SD0805S020S1R0_AVX_SD0805S020S1R0_0
D3, D4, D5: MBR0530; SOD3716X135N
D6, D8, D9, D10, D11, D12: PGB1010603MR; DIOC1608X36N
EPD_3V3, EPD_3V3_C: TPTP20R; TP20R
EPD_BUSY: TPTP20R; TP20R
EPD_C1, EPD_C2, EPD_C6, EPD_C7, EPD_C8, EPD_C9, EPD_C10, EPD_C11, EPD_C12: 1uF/50V; ESP32_WROVER_EAGLE-LTSPICE_C0402
EPD_C5: 0.1uF/50V; ESP32_WROVER_EAGLE-LTSPICE_C0402
EPD_CS: TPTP20R; TP20R
EPD_DC: TPTP20R; TP20R
EPD_RST: TPTP20R; TP20R
GHC_LED: ADAFRUIT_LEDCHIP-LED0603; ADAFRUIT_CHIP-LED0603
GND: TPTP20R; TP20R
GND_1: TPTP20R; TP20R
IC1: BD5229G-TR; SOT95P280X125-5N
IC4: XC6220A331MR-G; SOT95P280X120-5N
INT_RTC: TPTP20R; TP20R
J1: FH34SRJ-24S-0.5SH_99_; FH34SRJ24S05SH99
J2: SAMACSYS_PARTS_USB4110-GF-A; SAMACSYS_PARTS_USB4110GFA
J3: QWIIC_RIGHT_ANGLE; JST04_1MM_RA
J4: 112A-TAAR-R03_ATTEND; 112ATAARR03ATTEND
L1: 68uH; IND_4828-WE-TPC_WRE
MCP73831: ESP32_WROVER_SPARKFUN-IC-POWER_MCP73831; ESP32_WROVER_SPARKFUN-IC-POWER_SOT23-5
MISO: TPTP20R; TP20R
MOSI: TPTP20R; TP20R
PFMF.050.1: ESP32C6_VARISTORCN1812; ESP32C6_VARISTOR_CT/CN1812
Q1, Q2: 20V/4.2A/52mΩ/1.4W; ESP32_WROVER_SPARKFUN-DISCRETESEMI_SOT23-3
Q3: SI1308EDL-T1-GE3; SOT65P210X110-3N
R1, R1_PINH, R1_PINH1, R2-PINH, R2-PINH1, R4, R5, R6, R7, R8, R9, R10: 10K; ESP32_WROVER_EAGLE-LTSPICE_R0402
R1PWRUSB: 100K; ESP32_WROVER_EAGLE-LTSPICE_R0402
R1_BAT: 200; ESP32_WROVER_EAGLE-LTSPICE_R0402
R2: 2.2; ESP32_WROVER_EAGLE-LTSPICE_R0402
R2-USB, R2-USB1: 5k1; ESP32_WROVER_EAGLE-LTSPICE_R0402
R2_BAT: 2K; ESP32_WROVER_EAGLE-LTSPICE_R0402
R3: 0.47; ESP32_WROVER_EAGLE-LTSPICE_R0402
RESET_BUTTON: BUTTON_CUSYOMV1; MYBUTTON
RX: TPTP20R; TP20R
R_BOOT: 10K; ESP32_WROVER_EAGLE-LTSPICE_R0402
R_CAPACITOR: 15; ESP32_WROVER_EAGLE-LTSPICE_R0402
R_CHANGE: 10K; ESP32_WROVER_EAGLE-LTSPICE_R0402
R_CL1: 10K; ESP32_WROVER_EAGLE-LTSPICE_R0402
R_RESET: 10K; ESP32_WROVER_EAGLE-LTSPICE_R0402
SCK: TPTP20R; TP20R
SENSOR2: ESP32_WROVER_BME680_BME680; ESP32_WROVER_BME680_PSON80P300X300X100-8N
SJ1: SJ
TX: TPTP20R; TP20R
U1: W25Q512JVEIQ; SON127P600X800X80-9N
U2: ESP32-C6-WROOM-1-N8; XCVR_ESP32-C6-WROOM-1-N8
U3: DS3231SN#; SOIC127P1032X265-16N
U4: MAX17048G+T10; SON50P200X200X80-9N
VBAT: TPTP20R; TP20R
VBUS: TPTP20R; TP20R

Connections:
3V3: 3V3.TP, C1_BAT2.1, C3.+, C9.1, D7.2 (ANODE), IC1.2 (VDD), IC4.5 (VOUT), J3.2, J4.P4 (VDD), Q2.3 (D), R1.1, R1_PINH1.2, R2-PINH1.2, R5.2, R6.2, R7.2, R8.2, R9.2, R10.2, R_BOOT.1, R_CHANGE.1, R_CL1.1, R_RESET.1, U1.3 (!WP!(IO2)), U1.7 (!HOLD!/!RESET!(IO3)), U1.8 (VCC), U2.2 (3V3), U3.2 (VCC)
32KHZ: R2-PINH1.1, U2.9 (IO1), U3.1 (32KHZ)
DN: D1.4 (I/O2_2), J2.A7, J2.B7
DP: D1.6 (I/O1_2), J2.A6, J2.B6
EPD_3V3: C7.1, EPD_3V3.TP, EPD_C5.1, J1.15, J1.16, L1.2, Q2.2 (S)
EPD_3V3_C: EPD_3V3_C.TP, Q2.1 (G), R_CL1.2, U2.18 (IO20)
EPD_BUSY: EPD_BUSY.TP, J1.9, U2.26 (IO3)
EPD_CS: D6.1, EPD_CS.TP, J1.12, R9.1, U2.11 (IO10)
EPD_DC: EPD_DC.TP, J1.11, U2.5 (IO5)
EPD_RST: EPD_RST.TP, J1.10, U2.21 (IO23)
FLASH_CS: D9.1, R5.1, U1.1 (!CS), U2.12 (IO11)
GDR: J1.2, Q3.1 (G), R4.1
GND: BOOT_BUTTON.1, BOOT_BUTTON.2, C1.2, C1_BAT.2, C1_BAT1.2, C1_BAT2.2, C2.2, C2_BAT.2, C3.-, C4_USB.2, C5.2, C5_USB.2, C6.2, C7.2, C8.2, C9.2, C10.2, C10_SUPERCAP.1, CHANGE_BUTTON.1, CHANGE_BUTTON.2, C_DELAY.2, D1.2 (GND), D3.1 (K), D6.2, D8.2, D9.2, D10.2, D11.2, D12.2, EPD_C1.2, EPD_C2.2, EPD_C5.2, EPD_C6.2, EPD_C7.2, EPD_C8.2, EPD_C9.2, EPD_C10.2, EPD_C11.2, EPD_C12.2, GND.TP, GND_1.TP, IC1.3 (GND), IC4.2 (VSS), J1.8, J1.17, J1.MP1, J1.MP2, J2.A1, J2.A12, J2.B1, J2.B12, J2.MP1, J2.MP2, J2.MP3, J2.MP4, J3.1, J4.G1 (GND_1), J4.G2 (GND_2), J4.G3 (GND_3), J4.G4 (GND_4), J4.P6 (VSS), MCP73831.2 (VSS), R1PWRUSB.1, R2.1, R2-USB.2, R2-USB1.1, R2_BAT.2, R4.2, RESET_BUTTON.1, RESET_BUTTON.2, SENSOR2.1 (GND), SENSOR2.5 (SDO), SENSOR2.7 (GND), SJ1.1, U1.4 (GND), U1.9 (EXP), U2.1 (GND), U2.28 (GND), U2.29_1 (GND), U2.29_2 (GND), U2.29_3 (GND), U2.29_4 (GND), U2.29_5 (GND), U2.29_6 (GND), U2.29_7 (GND), U2.29_8 (GND), U2.29_9 (GND), U3.13 (GND), U4.1 (CTG), U4.4 (GND), U4.6 (QSTRT), U4.9 (EP)
GPIO8: R1.2, U2.10 (IO8)
I2C_PW: C1.1, C2.1, R1_PINH.2, R2-PINH.2, SENSOR2.2 (CSB), SENSOR2.6 (VDDIO), SENSOR2.8 (VDD), U2.17 (IO19)
INT_RTC: INT_RTC.TP, R1_PINH1.1, U2.8 (IO0), U3.3 (SQW/!INT)
IO/BOOT: BOOT_BUTTON.3, BOOT_BUTTON.4, C6.1, R_BOOT.2, U2.15 (IO9)
IO/CHANGE: C10.1, CHANGE_BUTTON.3, CHANGE_BUTTON.4, R_CHANGE.2, U2.23 (IO15)
MISO: D12.1, J4.P7 (DAT0), MISO.TP, R8.1, U1.2 (DO(IO1)), U2.27 (IO2)
MOSI: D11.1, J1.14, J4.P3 (CMD), MOSI.TP, R7.1, U1.5 (DI(IO0)), U2.7 (IO7)
unnamed: J2.B5, R2-USB.1
unnamed: J2.A5, R2-USB1.2
unnamed: C1_BAT1.1, D2.1 (CATHODE), IC4.1 (VIN), IC4.3 (CE), Q1.2 (S)
unnamed: EPD_C12.1, J1.24
unnamed: GHC_LED.C, R1_BAT.2
unnamed: C4.1, D3.2 (A), D4.1 (K)
unnamed: MCP73831.1 (STAT), R1_BAT.1
unnamed: MCP73831.5 (PROG), R2_BAT.1
unnamed: C_DELAY.1, IC1.5 (CT)
unnamed: EPD_C10.1, J1.22
unnamed: EPD_C8.1, J1.20
unnamed: EPD_C7.1, J1.19
unnamed: EPD_C6.1, J1.18
unnamed: EPD_C1.1, J1.4
unnamed: EPD_C2.1, J1.5
unnamed: D7.1 (CATHODE), R_CAPACITOR.1
PREVGH: D5.1 (K), EPD_C9.1, J1.21
PREVGL: D4.2 (A), EPD_C11.1, J1.23
RESE: J1.3, Q3.2 (S), R3.1
RESE': R2.2, R3.2, SJ1.2
RESET: C5.1, IC1.1 (VOUT), RESET_BUTTON.3, RESET_BUTTON.4, R_RESET.2, U2.3 (EN)
RTC_RST: U2.16 (IO18), U3.4 (!RST)
RX: RX.TP, U2.24 (RXD0/GPIO17)
SCK: D10.1, J1.13, J4.P5 (CLK), R6.1, SCK.TP, U1.6 (CLK), U2.6 (IO6)
SCL: J3.4, R2-PINH.1, SENSOR2.4 (SCK), U2.20 (IO22), U3.16 (SCL), U4.7 (SCL)
SDA: J3.3, R1_PINH.1, SENSOR2.3 (SDI), U2.19 (IO21), U3.15 (SDA), U4.8 (SDA)
SRC: C4.2, D5.2 (A), L1.1, Q3.3 (D)
SS_SD: D8.1, J4.P2 (CD/DAT3), R10.1, U2.4 (IO4)
TX: TX.TP, U2.25 (TXD0/GPIO16)
USB_D+: D1.1 (I/O1_1), U2.14 (IO13)
USB_D-: D1.3 (I/O2_1), U2.13 (IO12)
VBAT: C2_BAT.1, MCP73831.3 (VBAT), Q1.3 (D), U4.2 (CELL), U4.3 (VDD), VBAT.TP
VBUS: C1_BAT.1, C4_USB.1, C5_USB.1, D1.5 (VBUS), GHC_LED.A, MCP73831.4 (VIN), PFMF.050.1.2, VBUS.TP
VRTC: C8.1, C10_SUPERCAP.2, R_CAPACITOR.2, U3.14 (VBAT)
VUSB: D2.2 (ANODE), J2.A4, J2.A9, J2.B4, J2.B9, PFMF.050.1.1, Q1.1 (G), R1PWRUSB.2

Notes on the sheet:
USB C connector & ESD protection
LDO Voltage Regulator
SD Card
Display Type Selector
E-Paper Drive Circuit
Li-Po Battery Charging Controller
ESP32 C6
E-Paper Display Header
EPD Power
Enviromental Sensor BME688
Battery Charge Level
Voltage Supervisor + Reset & Boot / IO Button
Test Pads
Qwiic / Stemma QT
SPI ESD Protection Lines
External NOR Flash 64MB
RTC Module DS3231SN
Drawn by : Postolache Robert
4/3/2025
DeskAssistant v19
OpenBook Schematic

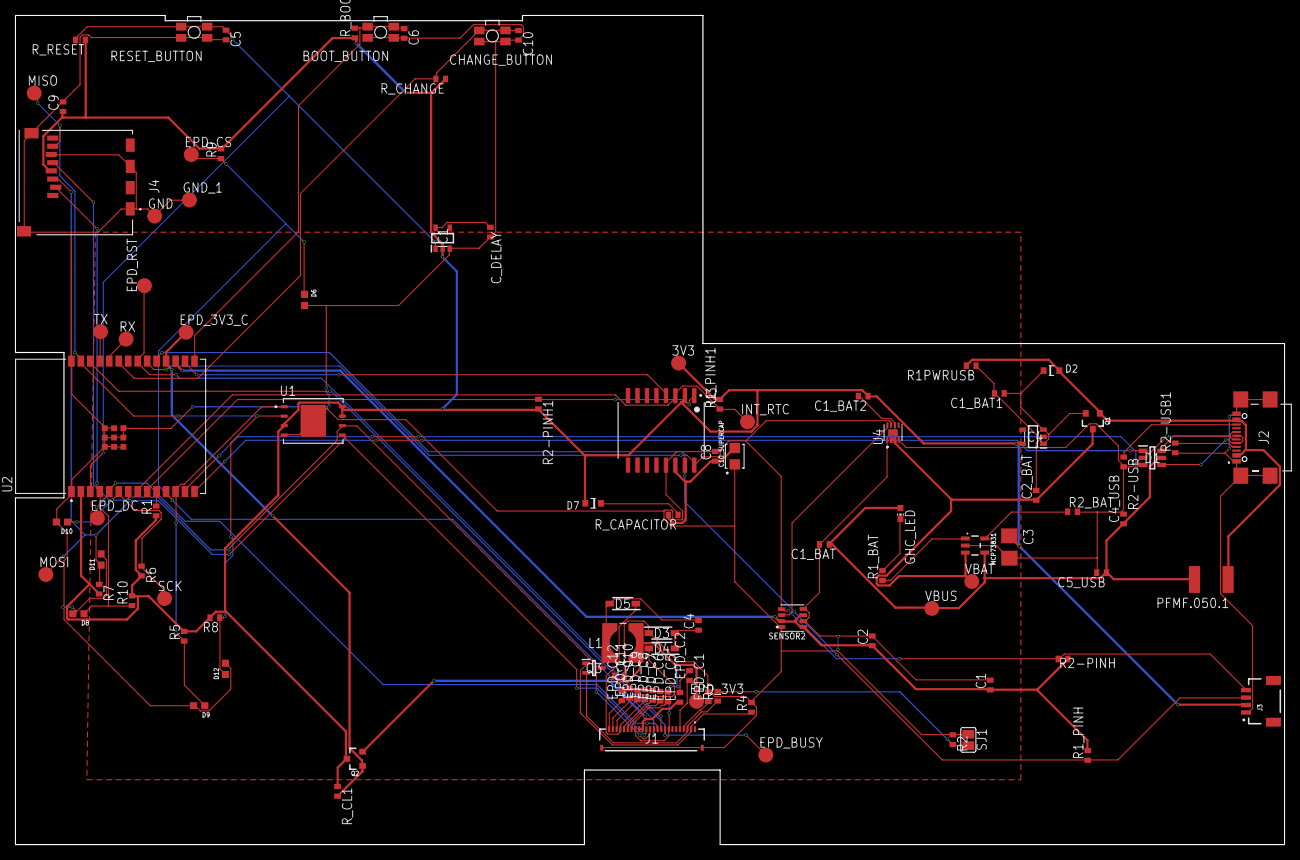
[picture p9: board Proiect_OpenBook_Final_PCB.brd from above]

Board: 2 copper layers, 170.2 x 111.2 mm, 103 parts (0 on the bottom side), 55 nets.

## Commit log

2025-04-06 schematic + pcb
    [Proiect_OpenBook V2 v1.brd, Proiect_OpenBook V2 v1.sch]
2025-04-14 Add files via upload
    Final
    [OpenBook Enclosure final.f3z]

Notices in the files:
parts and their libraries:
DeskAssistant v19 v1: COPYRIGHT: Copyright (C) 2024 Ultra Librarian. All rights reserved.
